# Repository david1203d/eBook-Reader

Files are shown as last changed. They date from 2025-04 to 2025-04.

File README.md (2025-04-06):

# 📘 Ebook Reader cu ESP32-C6

Acest proiect este un **Ebook Reader portabil**, cu consum redus, bazat pe **ESP32-C6** și ecran **E-Paper**, ideal pentru lectură prelungită.  
Dispozitivul citește fișiere `.txt` de pe un card **microSD** și permite navigarea cu **butoane fizice**, având alimentare din **baterie Li-Po** și opțional monitorizare a nivelului acesteia.

---

## 📦 Bill of Materials (BOM)

| Componentă | Model/Tip | Link comandă | Datasheet |
|---|---|---|---|
| Microcontroller | ESP32-C6 | Mouser | [ESP32-C6](#)  |
| Ecran | E-Paper Display 2.9" | Comet | [GDEH029A1](#) |
| Cart Reader | MicroSD SPI module | Mouser | [Modul SD](#)  |
| Senzor de mediu | BME688 | Mouser | [BME688](#) |
| RTC | DS3231SN | Mouser | [DS3231](#) |
| Battery Monitor | MAX17048 | Mouser | [MAX17048](#)  |
| Flash extern | W25Q512JV (64MB) | Mouser | [W25Q512JV](#) |
| Regulator tensiune | MCP1826S-3302E/DB | Mouser | [MCP1826](#) |
| BMS | TP4056 | Comet | [TP4056](#) |
| Butoane | Tactile Switches | Comet | [SKQG](#) |

---

## ⚙️ Funcționalitate Hardware

### 1. ESP32-C6
- Interfață principală: SPI, I2C, GPIO  
- Flash extern NOR (64MB) prin QSPI  
- UART pentru debug  
- Alimentare 3.3V prin LDO

### 2. E-Paper Display
- Alimentat prin EPD Power Driver (boost + FET)  
- Conectat prin SPI la ESP32-C6  
- Pini dedicați: DIN, CLK, CS, DC, RST, BUSY

### 3. Modul SD Card
- Interfață SPI  
- Stocare fișiere `.txt`

### 4. RTC DS3231SN
- I2C cu backup battery (CR2032)  
- Oră exactă cu temperatură compensată

### 5. Senzor BME688
- I2C – temperatură, presiune, umiditate, calitate aer  
- Util pentru monitorizare ambientală (opțional)

### 6. MAX17048
- Monitorizare nivel baterie prin I2C  
- Poate afișa procentul pe ecran

### 7. TP4056 Charging
- Încărcare Li-Po prin USB-C  
- Protecție la supradescărcare/supraincărcare

---

## 📌 Pini ESP32-C6 Utilizați

| Pin ESP32-C6 | Funcție hardware | Componentă |
|---|---|---|
| GPIO0 | I2C SCL | BME688, MAX17048, DS3231 |
| GPIO1 | I2C SDA | BME688, MAX17048, DS3231 |
| GPIO2 | SPI MOSI | E-paper, SD, Flash |
| GPIO3 | SPI MISO | SD, Flash |
| GPIO4 | SPI CLK | E-paper, SD, Flash |
| GPIO5 | SPI CS (e-paper) | E-paper |
| GPIO6 | SPI CS (SD card) | SD Card |
| GPIO7 | SPI CS (Flash extern) | W25Q512JV |
| GPIO8 | GPIO Buton 1 | Pag. înainte |
| GPIO9 | GPIO Buton 2 | Pag. înapoi |
| GPIO10 | GPIO Buton 3 | Reset/Menu |
| GPIO11 | UART TX | Debug UART |
| GPIO12 | UART RX | Debug UART |

---

## 🖼️ Design PCB & Randări

- **PCB**: 2 straturi, dimensiuni: `92.2mm x 67.2mm`  
- **Componente** poziționate compact pentru portabilitate  
- **Acces ușor** la card microSD, USB-C și butoane  
- **Protecție ESD** pe liniile USB și SPI  

## ✅ Alte Detalii Relevante

- **Mod Deep Sleep**: activat după 30s de inactivitate  
- **W25Q512JV Flash extern**: stocare rapidă pentru sute de cărți `.txt`  
- **Qwiic/Stemma QT header**: pentru expansiune cu alte periferice  
- **Test Pads**: depanare & validare semnal

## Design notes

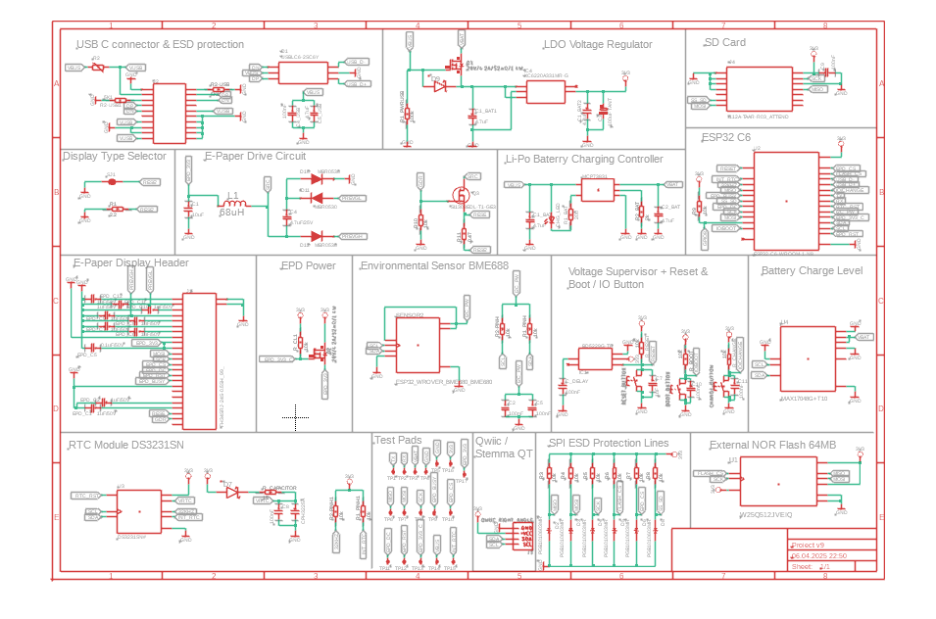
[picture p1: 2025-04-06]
Images/Schematic.PNG

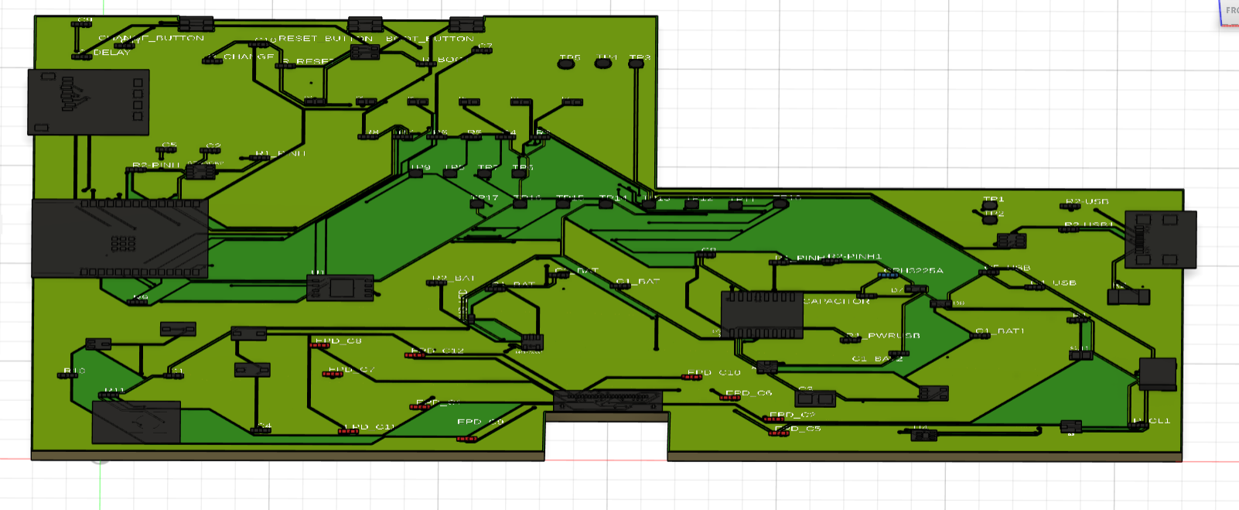
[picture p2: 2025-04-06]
Images/Placa3D.PNG

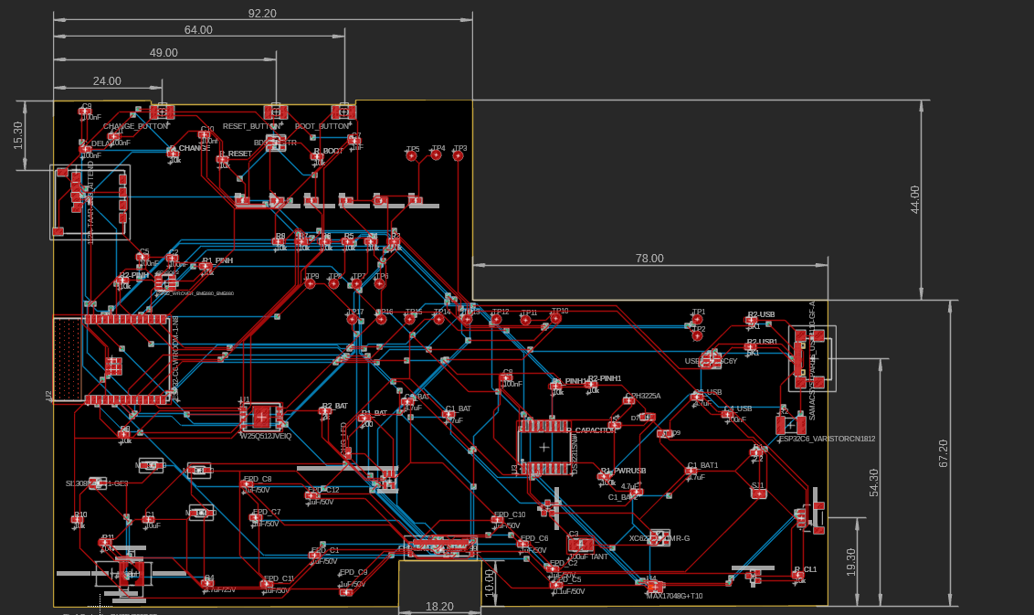
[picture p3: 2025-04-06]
Images/PCB.png

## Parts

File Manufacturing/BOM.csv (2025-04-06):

Qty | Value | Device | Package | Parts | Description | ARROW_PART_NUMBER | ARROW_PRICE-STOCK | AVAILABILITY | CENTROID_NOT_SPECIFIED | CHECK_PRICES | COPYRIGHT | DATASHEET | DESCRIPTION | DIGIKEY_DESCRIPTION | DIGIKEY_PART_NUMBER | HEIGHT | LEAD_FREE | MANUFACTURER_NAME | MANUFACTURER_PART_NUMBER | MF | MFR_NAME | MOUSER_PART_NUMBER | MOUSER_PRICE-STOCK | MOUSER_TESTING_PART_NUMBER | MOUSER_TESTING_PRICE-STOCK | MP | MPN | PACKAGE | POPULARITY | PREFIX | PRICE | PROD_ID | PURCHASE-URL | ROHS | SNAPEDA_LINK | SPICEMODEL | SPICEPREFIX | TEMPERATURE_RANGE_HIGH | TEMPERATURE_RANGE_LOW | TP_SIGNAL_NAME | VALUE
1 |  | ADAFRUIT_LEDCHIP-LED0603 | ADAFRUIT_CHIP-LED0603 | CHG_LED | LED
1 |  | EAGLE-LTSPICE_CC0402 | EAGLE-LTSPICE_C0402 | CPH3225A | CAPACITOR, European symbol |  |  |  |  |  |  |  |  |  |  |  |  |  |  |  |  |  |  |  |  |  |  |  |  |  |  |  |  |  |  | NONE | C
1 |  | SJ | SJ | SJ1 | SMD solder JUMPER |  |  |  |  |  |  |  |  |  |  |  |  |  |  |  |  |  |  |  |  |  |  |  | 3
1 | 0.1uF/50V | EAGLE-LTSPICE_CC0402 | EAGLE-LTSPICE_C0402 | EPD_C5 | CAPACITOR, European symbol |  |  |  |  |  |  |  |  |  |  |  |  |  |  |  |  |  |  |  |  |  |  |  |  |  |  |  |  |  |  | NONE | C
1 | 0.47 | ESP32_WROVER_EAGLE-LTSPICE_RR0402 | ESP32_WROVER_EAGLE-LTSPICE_R0402 | R11 | RESISTOR, European symbol |  |  |  |  |  |  |  |  |  |  |  |  |  |  |  |  |  |  |  |  |  |  |  |  |  |  |  |  |  |  | NONE | R
1 | 100k | ESP32_WROVER_EAGLE-LTSPICE_RR0402 | ESP32_WROVER_EAGLE-LTSPICE_R0402 | R1_PWRUSB | RESISTOR, European symbol |  |  |  |  |  |  |  |  |  |  |  |  |  |  |  |  |  |  |  |  |  |  |  |  |  |  |  |  |  |  | NONE | R
1 | 100nF | EAGLE-LTSPICE_CC0402 | EAGLE-LTSPICE_C0402 | C8 | CAPACITOR, European symbol |  |  |  |  |  |  |  |  |  |  |  |  |  |  |  |  |  |  |  |  |  |  |  |  |  |  |  |  |  |  | NONE | C
6 | 100nF | ESP32_WROVER_EAGLE-LTSPICE_CC0402 | ESP32_WROVER_EAGLE-LTSPICE_C0402 | C2, C4_USB, C5, C9, C11, C_DELAY | CAPACITOR, European symbol |  |  |  |  |  |  |  |  |  |  |  |  |  |  |  |  |  |  |  |  |  |  |  |  |  |  |  |  |  |  | NONE | C
1 | 100nf | ESP32_WROVER_EAGLE-LTSPICE_CC0402 | ESP32_WROVER_EAGLE-LTSPICE_C0402 | C10 | CAPACITOR, European symbol |  |  |  |  |  |  |  |  |  |  |  |  |  |  |  |  |  |  |  |  |  |  |  |  |  |  |  |  |  |  | NONE | C
1 | 100uF TANT | RCL_CPOL-EUCT3528 | RCL_CT3528 | C3 | POLARIZED CAPACITOR, European symbol |  |  |  |  |  |  |  |  |  |  |  |  |  |  |  |  |  |  |  |  |  |  |  | 0 |  |  |  |  |  |  |  | C
16 | 10k | ESP32_WROVER_EAGLE-LTSPICE_RR0402 | ESP32_WROVER_EAGLE-LTSPICE_R0402 | R1_PINH, R1_PINH1, R2-PINH, R2-PINH1, R3, R4, R5, R6, R7, R8, R9, R10, R_BOOT, R_CHANGE, R_CL1, R_RESET | RESISTOR, European symbol |  |  |  |  |  |  |  |  |  |  |  |  |  |  |  |  |  |  |  |  |  |  |  |  |  |  |  |  |  |  | NONE | R
1 | 10uF | ESP32_WROVER_EAGLE-LTSPICE_CC0402 | ESP32_WROVER_EAGLE-LTSPICE_C0402 | C1 | CAPACITOR, European symbol |  |  |  |  |  |  |  |  |  |  |  |  |  |  |  |  |  |  |  |  |  |  |  |  |  |  |  |  |  |  | NONE | C
1 | 112A-TAAR-R03_ATTEND | 112A-TAAR-R03_ATTEND | 112ATAARR03ATTEND | J4 | Micro SD Card Socket, Push-Push Type, Top Mount, SMT, H=1.83mm, 10u |  |  |  |  |  |  |  | Micro SD Card Socket | Push-Push Type | Top Mount | SMT | H=1.83mm | 10u |  |  | 1.9mm |  | ATTEND | 112A-TAAR-R03 ATTEND
1 | 15 | ESP32_WROVER_EAGLE-LTSPICE_RR0402 | ESP32_WROVER_EAGLE-LTSPICE_R0402 | R_CAPACITOR | RESISTOR, European symbol |  |  |  |  |  |  |  |  |  |  |  |  |  |  |  |  |  |  |  |  |  |  |  |  |  |  |  |  |  |  | NONE | R
1 | 1uF | ESP32_WROVER_EAGLE-LTSPICE_CC0402 | ESP32_WROVER_EAGLE-LTSPICE_C0402 | C7 | CAPACITOR, European symbol |  |  |  |  |  |  |  |  |  |  |  |  |  |  |  |  |  |  |  |  |  |  |  |  |  |  |  |  |  |  | NONE | C
9 | 1uF/50V | EAGLE-LTSPICE_CC0402 | EAGLE-LTSPICE_C0402 | EPD_C1, EPD_C2, EPD_C6, EPD_C7, EPD_C8, EPD_C9, EPD_C10, EPD_C11, EPD_C12 | CAPACITOR, European symbol |  |  |  |  |  |  |  |  |  |  |  |  |  |  |  |  |  |  |  |  |  |  |  |  |  |  |  |  |  |  | NONE | C
1 | 2.2 | ESP32_WROVER_EAGLE-LTSPICE_RR0402 | ESP32_WROVER_EAGLE-LTSPICE_R0402 | R1 | RESISTOR, European symbol |  |  |  |  |  |  |  |  |  |  |  |  |  |  |  |  |  |  |  |  |  |  |  |  |  |  |  |  |  |  | NONE | R
1 | 200 | ESP32_WROVER_EAGLE-LTSPICE_RR0402 | ESP32_WROVER_EAGLE-LTSPICE_R0402 | R1_BAT | RESISTOR, European symbol |  |  |  |  |  |  |  |  |  |  |  |  |  |  |  |  |  |  |  |  |  |  |  |  |  |  |  |  |  |  | NONE | R
2 | 20V/4.2A/52mO/1.4W | ESP32_WROVER_SPARKFUN-DISCRETESEMI_MOSFET_PCH-DMG2305UX-7 | ESP32_WROVER_SPARKFUN-DISCRETESEMI_SOT23-3 | Q1, Q2 | P-channel MOSFETs |  |  |  |  |  |  |  |  |  |  |  |  |  |  |  |  |  |  |  |  |  |  |  |  |  |  | TRAN-14388 |  |  |  |  |  |  |  |  | 20V/4.2A/52mO/1.4W
1 | 2k | ESP32_WROVER_EAGLE-LTSPICE_RR0402 | ESP32_WROVER_EAGLE-LTSPICE_R0402 | R2_BAT | RESISTOR, European symbol |  |  |  |  |  |  |  |  |  |  |  |  |  |  |  |  |  |  |  |  |  |  |  |  |  |  |  |  |  |  | NONE | R
5 | 4.7uF | ESP32_WROVER_EAGLE-LTSPICE_CC0402 | ESP32_WROVER_EAGLE-LTSPICE_C0402 | C1_BAT, C1_BAT1, C1_BAT2, C2_BAT, C5_USB | CAPACITOR, European symbol |  |  |  |  |  |  |  |  |  |  |  |  |  |  |  |  |  |  |  |  |  |  |  |  |  |  |  |  |  |  | NONE | C
1 | 4.7uF/25V | ESP32_WROVER_EAGLE-LTSPICE_CC0402 | ESP32_WROVER_EAGLE-LTSPICE_C0402 | C4 | CAPACITOR, European symbol |  |  |  |  |  |  |  |  |  |  |  |  |  |  |  |  |  |  |  |  |  |  |  |  |  |  |  |  |  |  | NONE | C
2 | 5K1 | ESP32_WROVER_EAGLE-LTSPICE_RR0402 | ESP32_WROVER_EAGLE-LTSPICE_R0402 | R2-USB, R2-USB1 | RESISTOR, European symbol |  |  |  |  |  |  |  |  |  |  |  |  |  |  |  |  |  |  |  |  |  |  |  |  |  |  |  |  |  |  | NONE | R
1 | 68uH | 744043680IND_4828-WE-TPC_WRE | IND_4828-WE-TPC_WRE | L1 |  |  |  |  |  |  | Copyright (C) 2024 Ultra Librarian. All rights reserved. |  |  |  |  |  |  |  | 744043680 |  | Wurth Electronics
1 | BD5229G-TR | BD5229G-TR | SOT95P280X125-5N | IC1 | Voltage Detector with Adjustable Delay Time: CMOS processes are utilized to develop high precision, low current consumption CMOS reset ICs that allow arbitrary setting of the delay time. The extensive lineup includes both Nch Open Drain and CMOS output types in a wide range of detection voltages (from 2.3V to 6.0V, in 0.1V steps), enabling selection of the ideal solution based on customer requirements. In addition, the entire series is of course both lead-free and RoHS-compliant. |  |  |  |  |  |  |  | Voltage Detector with Adjustable Delay Time: CMOS processes are utilized to develop high precision | low current consumption CMOS reset ICs that allow arbitrary setting of the delay time. The extensive lineup includes both Nch Open Drain and CMOS output types in a wide range of detection voltages (from 2.3V to 6.0V | in 0.1V steps) | enabling selection of the ideal solution based on customer requirements. In addition | the entire series is of course both lead-free and RoHS-compliant. |  |  | 1.25mm |  | ROHM Semiconductor | BD5229G-TR |  |  | 755-BD5229G-TR | https://www.mouser.co.uk/ProductDetail/ROHM-Semiconductor/BD5229G-TR?qs=4kLU8WoGk0vvnhrrYwdszw%3D%3D
3 | BUTTON_CUSYOMV1 | BUTTON_CUSYOMV1 | MYBUTTON | BOOT_BUTTON, CHANGE_BUTTON, RESET_BUTTON
1 | DS3231SN# | DS3231SN# | SOIC127P1032X265-16N | U3 | Real Time Clock Serial 16-Pin SOIC W T/R Check availability |  |  | In Stock |  | https://www.snapeda.com/parts/DS3231SN%23/Analog+Devices/view-part/?ref=eda |  |  | Extremely Accurate I²C-Integrated RTC/TCXO/Crystal |  |  |  |  |  |  | Analog Devices |  |  |  |  |  | DS3231SN# |  | SOIC-16 Maxim |  |  | None |  | https://www.snapeda.com/api/url_track_click_mouser/?unipart_id=99048&manufacturer=Analog Devices&part_name=DS3231SN#&search_term=None |  | https://www.snapeda.com/parts/DS3231SN%23/Analog+Devices/view-part/?ref=snap
1 | ESP32-C6-WROOM-1-N8 | ESP32-C6-WROOM-1-N8 | XCVR_ESP32-C6-WROOM-1-N8 | U2 | Check availability |  |  | In Stock |  | https://www.snapeda.com/parts/ESP32-C6-WROOM-1-N8/Espressif+Systems/view-part/?ref=eda |  |  | Multiprotocol Modules ESP32-C6 module | Wi-Fi 6 in 2.4 GHz band | Bluetooth 5 | Zigbee 3.0 and Thread. ESP34-WROOM Compatible - ENGINEERING SAMPLE |  |  |  |  |  |  | Espressif Systems |  |  |  |  |  | ESP32-C6-WROOM-1-N8 |  | None |  |  | None |  |  |  | https://www.snapeda.com/parts/ESP32-C6-WROOM-1-N8/Espressif+Systems/view-part/?ref=snap
1 | ESP32C6_VARISTORCN1812 | ESP32C6_VARISTORCN1812 | ESP32C6_VARISTOR_CT/CN1812 | R2 | VARISTOR |  |  |  |  |  |  |  |  |  |  |  |  |  |  |  |  |  |  |  |  |  |  |  | 0
2 | ESP32_WROVER_AVX---SD0805S020S1R0_AVX_SD0805S020S1R0_0_0AVX_SD0805S020S1R0_0_0 | ESP32_WROVER_AVX---SD0805S020S1R0_AVX_SD0805S020S1R0_0_0AVX_SD0805S020S1R0_0_0 | ESP32_WROVER_AVX---SD0805S020S1R0_AVX_SD0805S020S1R0_0 | D7, D9 | Schottky Barrier Rectifier Diode |  |  |  | No |  |  | http://datasheets.avx.com/schottky.pdf |  | DIODE SCHOTTKY 20V 1A 0805 | 478-7800-1-ND |  | yes |  |  | AVX |  | 581-SD0805S020S1R0 |  |  |  |  |  | 0805 (2012 metric) |  | D |  |  |  | yes |  |  |  | +125°C | -55°C
1 | ESP32_WROVER_BME680_BME680 | ESP32_WROVER_BME680_BME680 | ESP32_WROVER_BME680_PSON80P300X300X100-8N | SENSOR2 | Integrated Environmental Unit |  |  | Unavailable |  |  |  |  | Integrated Environmental Unit |  |  |  |  |  |  | Bosch Sensortec |  |  |  |  |  | BME680 |  | LGA-8 Bosch Tools |  |  | None
1 | ESP32_WROVER_SPARKFUN-IC-POWER_MCP73831 | ESP32_WROVER_SPARKFUN-IC-POWER_MCP73831 | ESP32_WROVER_SPARKFUN-IC-POWER_SOT23-5 | MCP73831 | MCP73831T Li-Ion, Li-Pol Controller |  |  |  |  |  |  |  |  |  |  |  |  |  |  |  |  |  |  |  |  |  |  |  |  |  |  | IC-09995
1 | FH34SRJ-24S-0.5SH_99_ | FH34SRJ-24S-0.5SH_99_ | FH34SRJ24S05SH99 | J1 | (0.50mm) Surface Mount, Right Angle |  |  |  |  |  |  |  | 24 Position FFC | FPC Connector Contacts | (0.50mm) Surface Mount | Right Angle |  |  | 1.1mm |  | Hirose | FH34SRJ-24S-0.5SH(99) |  |  | 798-FH34SRJ24S05SH99 | https://www.mouser.co.uk/ProductDetail/Hirose-Connector/FH34SRJ-24S-0.5SH99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
1 | MAX17048G+T10 | MAX17048G+T10 | SON50P200X200X80-9N | U4 | Check availability |  |  | In Stock |  | https://www.snapeda.com/parts/MAX17048G+T10/Analog+Devices/view-part/?ref=eda |  |  | 3µA 1-Cell/2-Cell Fuel Gauge with ModelGauge |  |  |  |  |  |  | Analog Devices |  |  |  |  |  | MAX17048G+T10 |  | TDFN-8 Maxim |  |  | None |  | https://www.snapeda.com/api/url_track_click_mouser/?unipart_id=329239&manufacturer=Analog Devices&part_name=MAX17048G+T10&search_term=None |  | https://www.snapeda.com/parts/MAX17048G+T10/Analog+Devices/view-part/?ref=snap
3 | MBR0530 | MBR0530 | SOD3716X135N | D10, D11, D12 | ON SEMICONDUCTOR - MBR0530 - DIODE, SCHOTTKY, 0.5A, 30V, SOD-123 |  |  | In Stock |  | https://www.snapeda.com/parts/MBR0530/Onsemi/view-part/?ref=eda |  |  | Diode Schottky 30 V 500mA Surface Mount SOD-123 |  |  |  |  |  |  | ON Semiconductor |  |  |  |  |  | MBR0530 |  | SOD-123-2 ON Semiconductor |  |  | None |  | https://www.snapeda.com/api/url_track_click_mouser/?unipart_id=179458&manufacturer=ON Semiconductor&part_name=MBR0530&search_term=None |  | https://www.snapeda.com/parts/MBR0530/Onsemi/view-part/?ref=snap
6 | PGB1010603MR | PGB1010603MR | DIOC1608X36N | D2, D3, D4, D5, D6, D8 | Check availability |  |  | In Stock |  | https://www.snapeda.com/parts/PGB1010603MR/Littelfuse/view-part/?ref=eda |  |  | 150V (Typ) Clamp - Ipp Tvs Diode Surface Mount 0603 (1608 Metric) |  |  |  |  |  |  | Littelfuse Inc. |  |  |  |  |  | PGB1010603MR |  | 0603 Littelfuse Inc. |  |  | None |  | https://www.snapeda.com/api/url_track_click_mouser/?unipart_id=5659453&manufacturer=Littelfuse Inc.&part_name=PGB1010603MR&search_term=None |  | https://www.snapeda.com/parts/PGB1010603MR/Littelfuse/view-part/?ref=snap
1 | QWIIC_RIGHT_ANGLE | QWIIC_CONNECTORJS-1MM | JST04_1MM_RA | J3 | SparkFun I2C Standard Qwiic Connector |  |  |  |  |  |  |  |  |  |  |  |  |  |  |  |  |  |  |  |  |  |  |  |  |  |  | CONN-13694 |  |  |  |  |  |  |  |  | QWIIC_RIGHT_ANGLE
1 | SAMACSYS_PARTS_USB4110-GF-A | SAMACSYS_PARTS_USB4110-GF-A | SAMACSYS_PARTS_USB4110GFA | J2 | CONN USB 2.0 TYPE-C R/A SMT |  |  |  |  |  |  |  | CONN USB 2.0 TYPE-C R/A SMT |  |  | 3.26mm |  | GCT (GLOBAL CONNECTOR TECHNOLOGY) | USB4110-GF-A |  |  | 640-USB4110-GF-A | https://www.mouser.co.uk/ProductDetail/GCT/USB4110-GF-A?qs=KUoIvG%2F9IlYiZvIXQjyJeA%3D%3D
1 | SI1308EDL-T1-GE3 | SI1308EDL-T1-GE3 | SOT65P210X110-3N | Q3 | MOSFET N-Ch 30V 1.5A TrenchFET SC70 Vishay Si1308EDL-T1-GE3 N-channel MOSFET Transistor, 1.5 A, 30 V, 3-Pin SC-70 |  |  | In Stock |  | https://www.snapeda.com/parts/SI1308EDL-T1-GE3/Vishay+Siliconix/view-part/?ref=eda |  |  | Si1308EDL-T1-GE3 N-channel MOSFET Transistor | 1.5 A | 30 V | 3-Pin SC-70 | Siliconix / Vishay SI1308EDL-T1-GE3 |  |  |  |  |  |  | Vishay Siliconix |  |  |  |  |  | SI1308EDL-T1-GE3 |  | SOT-323 Vishay Semiconductor |  |  | None |  | https://www.snapeda.com/api/url_track_click_mouser/?unipart_id=274603&manufacturer=Vishay Siliconix&part_name=SI1308EDL-T1-GE3&search_term=None |  | https://www.snapeda.com/parts/SI1308EDL-T1-GE3/Vishay+Siliconix/view-part/?ref=snap
17 | TPTP20R | TPTP20R | TP20R | TP1, TP2, TP3, TP4, TP5, TP6, TP7, TP8, TP9, TP10, TP11, TP12, TP13, TP14, TP15, TP16, TP17 | Test pad |  |  |  |  |  |  |  |  |  |  |  |  |  |  |  |  |  |  |  |  |  |  |  | 2
1 | USBLC6-2SC6Y | USBLC6-2SC6Y | SOT95P280X145-6N | D1 | Low Cap. ESD Protection Auto SOT-23-6 STMicroelectronics USBLC6-2SC6Y, Dual Uni-Directional TVS Diode Array, 6-Pin SOT-23 |  |  | In Stock |  | https://www.snapeda.com/parts/USBLC6-2SC6Y/STMicroelectronics/view-part/?ref=eda |  |  | 17V Clamp 5A (8/20µs) Ipp Tvs Diode Surface Mount SOT-23-6 |  |  |  |  |  |  | STMicroelectronics |  |  |  |  |  | USBLC6-2SC6Y |  | SOT-23-6 STMicroelectronics |  |  | None |  |  |  | https://www.snapeda.com/parts/USBLC6-2SC6Y/STMicroelectronics/view-part/?ref=snap
1 | W25Q512JVEIQ | W25Q512JVEIQ | SON127P600X800X80-9N | U1 | Check availability |  |  | In Stock |  | https://www.snapeda.com/parts/W25Q512JVEIQ/Winbond+Electronics/view-part/?ref=eda |  |  | FLASH - NOR Memory IC 512Mb (64M x 8) SPI - Quad I/O 133 MHz 8-WSON (8x6) |  |  |  |  |  |  | Winbond Electronics |  |  |  |  |  | W25Q512JVEIQ |  | Package |  |  | None |  |  |  | https://www.snapeda.com/parts/W25Q512JVEIQ/Winbond+Electronics/view-part/?ref=snap
1 | XC6220A331MR-G | XC6220A331MR-G | SOT95P280X120-5N | IC4 | LDO Voltage Regulators |  |  |  |  |  |  |  | LDO Voltage Regulators |  |  | 1.2mm |  | Torex | XC6220A331MR-G |  |  | 865-XC6220A331MR-G | https://www.mouser.co.uk/ProductDetail/Torex-Semiconductor/XC6220A331MR-G?qs=AsjdqWjXhJ8ZSWznL1J0gg%3D%3D

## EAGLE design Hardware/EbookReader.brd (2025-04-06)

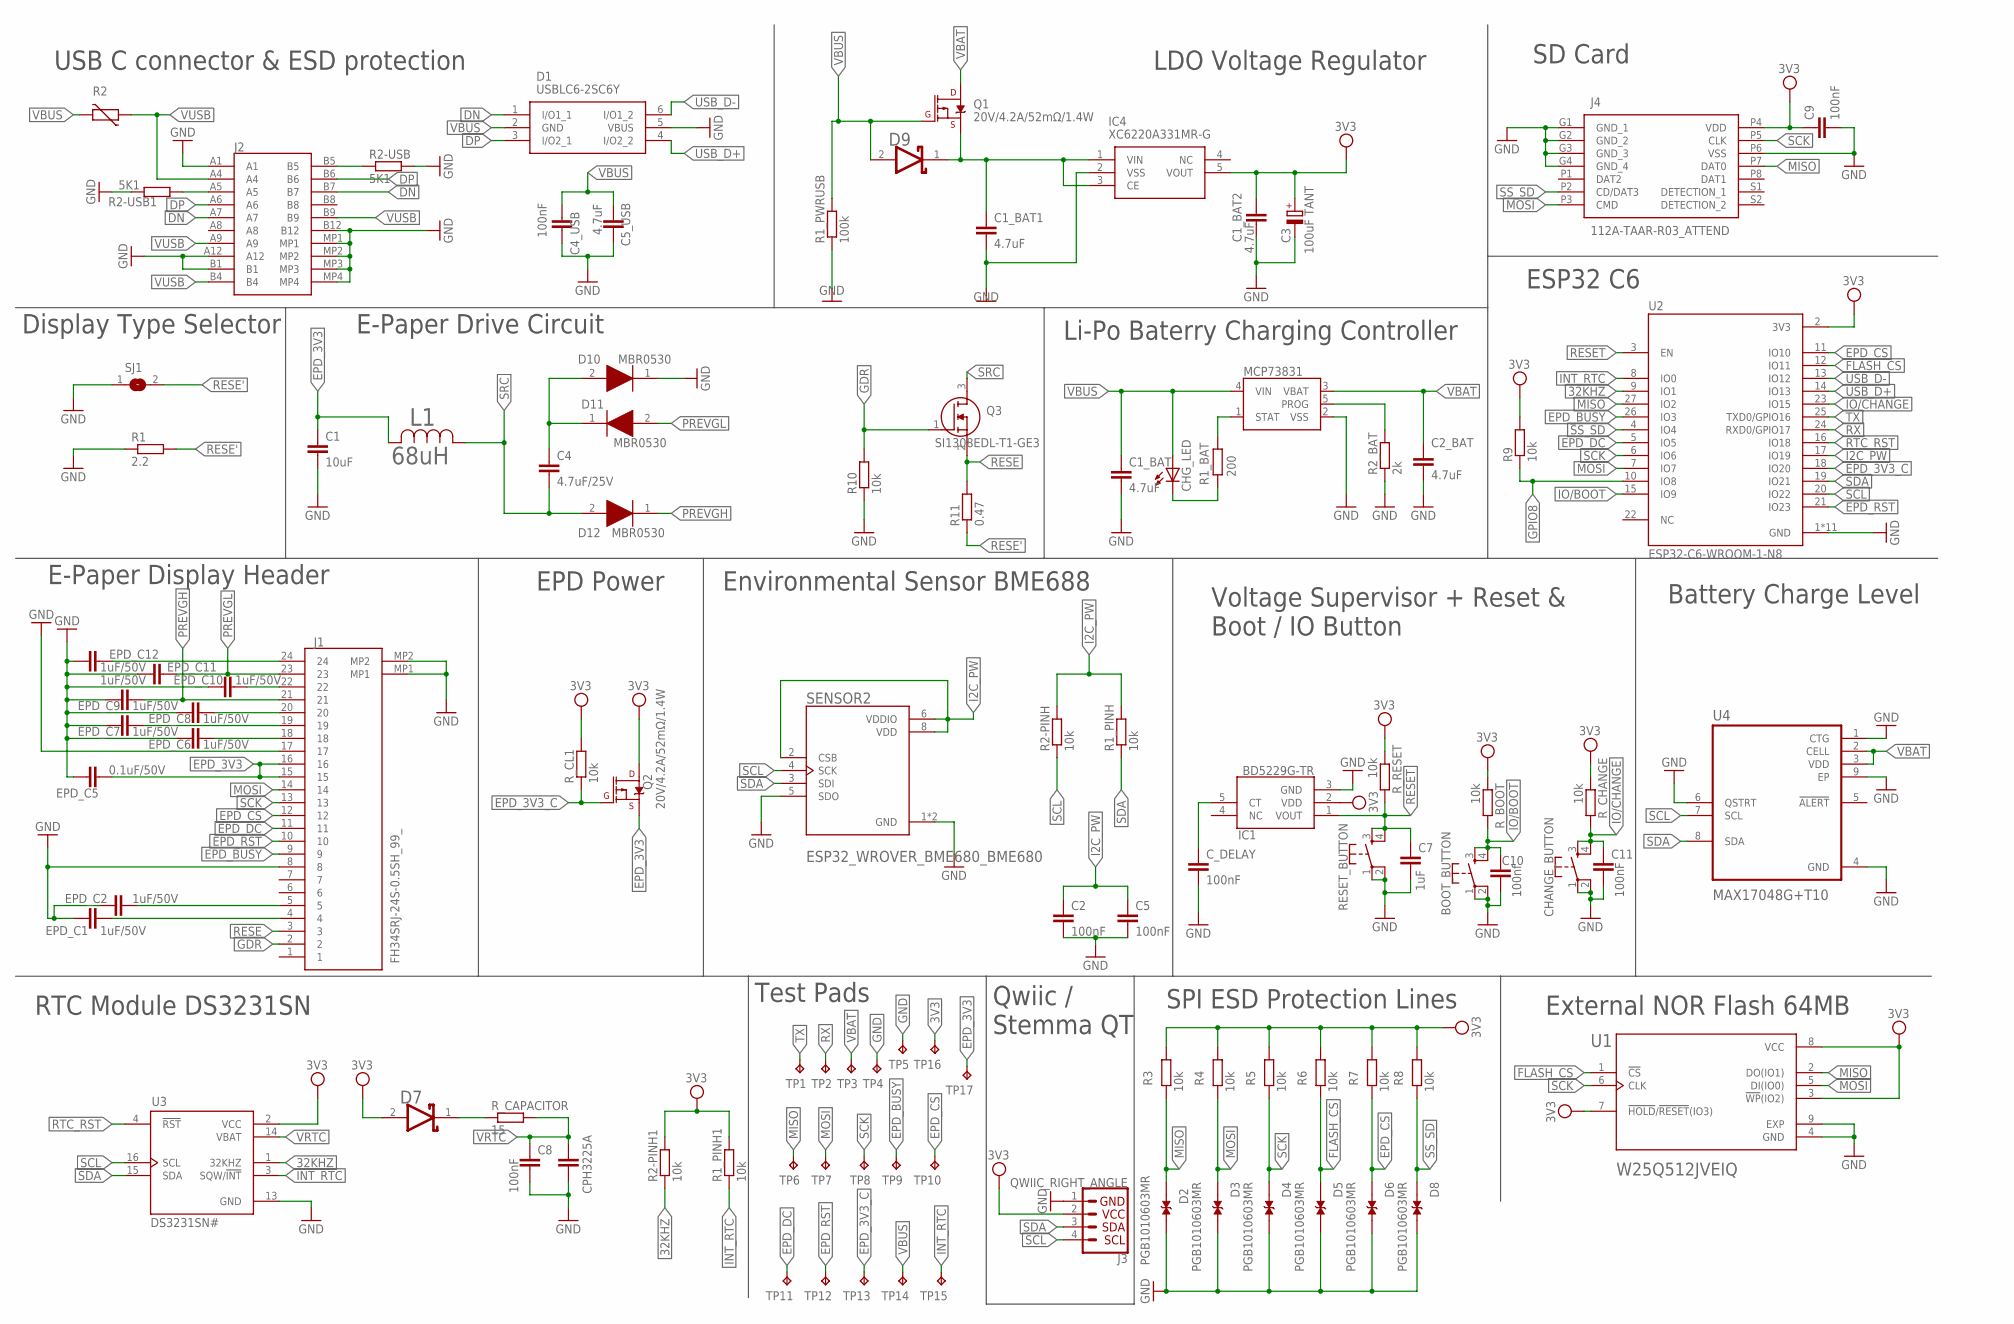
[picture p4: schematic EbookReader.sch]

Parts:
BOOT_BUTTON: BUTTON_CUSYOMV1; MYBUTTON
C1: 10uF; ESP32_WROVER_EAGLE-LTSPICE_C0402
C1_BAT, C1_BAT1, C1_BAT2, C2_BAT, C5_USB: 4.7uF; ESP32_WROVER_EAGLE-LTSPICE_C0402
C2, C4_USB, C5, C9, C11: 100nF; ESP32_WROVER_EAGLE-LTSPICE_C0402
C3: 100uF TANT; RCL_CT3528
C4: 4.7uF/25V; ESP32_WROVER_EAGLE-LTSPICE_C0402
C7: 1uF; ESP32_WROVER_EAGLE-LTSPICE_C0402
C8: 100nF; EAGLE-LTSPICE_C0402
C10: 100nf; ESP32_WROVER_EAGLE-LTSPICE_C0402
CHANGE_BUTTON: BUTTON_CUSYOMV1; MYBUTTON
CHG_LED: ADAFRUIT_LEDCHIP-LED0603; ADAFRUIT_CHIP-LED0603
CPH3225A: EAGLE-LTSPICE_CC0402; EAGLE-LTSPICE_C0402
C_DELAY: 100nF; ESP32_WROVER_EAGLE-LTSPICE_C0402
D1: USBLC6-2SC6Y; SOT95P280X145-6N
D2, D3, D4, D5, D6, D8: PGB1010603MR; DIOC1608X36N
D7, D9: ESP32_WROVER_AVX---SD0805S020S1R0_AVX_SD0805S020S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; ESP32_WROVER_AVX---SD0805S020S1R0_AVX_SD0805S020S1R0_0
D10, D11, D12: MBR0530; SOD3716X135N
EPD_C1, EPD_C2, EPD_C6, EPD_C7, EPD_C8, EPD_C9, EPD_C10, EPD_C11, EPD_C12: 1uF/50V; EAGLE-LTSPICE_C0402
EPD_C5: 0.1uF/50V; EAGLE-LTSPICE_C0402
IC1: BD5229G-TR; SOT95P280X125-5N
IC4: XC6220A331MR-G; SOT95P280X120-5N
J1: FH34SRJ-24S-0.5SH_99_; FH34SRJ24S05SH99
J2: SAMACSYS_PARTS_USB4110-GF-A; SAMACSYS_PARTS_USB4110GFA
J3: QWIIC_RIGHT_ANGLE; JST04_1MM_RA
J4: 112A-TAAR-R03_ATTEND; 112ATAARR03ATTEND
L1: 68uH; IND_4828-WE-TPC_WRE
MCP73831: ESP32_WROVER_SPARKFUN-IC-POWER_MCP73831; ESP32_WROVER_SPARKFUN-IC-POWER_SOT23-5
Q1, Q2: 20V/4.2A/52mΩ/1.4W; ESP32_WROVER_SPARKFUN-DISCRETESEMI_SOT23-3
Q3: SI1308EDL-T1-GE3; SOT65P210X110-3N
R1: 2.2; ESP32_WROVER_EAGLE-LTSPICE_R0402
R1_BAT: 200; ESP32_WROVER_EAGLE-LTSPICE_R0402
R1_PINH, R1_PINH1, R2-PINH, R2-PINH1, R3, R4, R5, R6, R7, R8, R9, R10: 10k; ESP32_WROVER_EAGLE-LTSPICE_R0402
R1_PWRUSB: 100k; ESP32_WROVER_EAGLE-LTSPICE_R0402
R2: ESP32C6_VARISTORCN1812; ESP32C6_VARISTOR_CT/CN1812
R2-USB, R2-USB1: 5K1; ESP32_WROVER_EAGLE-LTSPICE_R0402
R2_BAT: 2k; ESP32_WROVER_EAGLE-LTSPICE_R0402
R11: 0.47; ESP32_WROVER_EAGLE-LTSPICE_R0402
RESET_BUTTON: BUTTON_CUSYOMV1; MYBUTTON
R_BOOT: 10k; ESP32_WROVER_EAGLE-LTSPICE_R0402
R_CAPACITOR: 15; ESP32_WROVER_EAGLE-LTSPICE_R0402
R_CHANGE: 10k; ESP32_WROVER_EAGLE-LTSPICE_R0402
R_CL1: 10k; ESP32_WROVER_EAGLE-LTSPICE_R0402
R_RESET: 10k; ESP32_WROVER_EAGLE-LTSPICE_R0402
SENSOR2: ESP32_WROVER_BME680_BME680; ESP32_WROVER_BME680_PSON80P300X300X100-8N
SJ1: SJ
TP1, TP2, TP3, TP4, TP5, TP6, TP7, TP8, TP9, TP10, TP11, TP12, TP13, TP14, TP15, TP16, TP17: TPTP20R; TP20R
U1: W25Q512JVEIQ; SON127P600X800X80-9N
U2: ESP32-C6-WROOM-1-N8; XCVR_ESP32-C6-WROOM-1-N8
U3: DS3231SN#; SOIC127P1032X265-16N
U4: MAX17048G+T10; SON50P200X200X80-9N

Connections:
3V3: C1_BAT2.1, C3.+, C9.1, D7.2 (ANODE), IC1.2 (VDD), IC4.5 (VOUT), J3.2, J4.P4 (VDD), Q2.3 (D), R1_PINH1.2, R2-PINH1.2, R3.2, R4.2, R5.2, R6.2, R7.2, R8.2, R9.2, R_BOOT.1, R_CHANGE.1, R_CL1.2, R_RESET.1, TP16.TP, U1.3 (!WP!(IO2)), U1.7 (!HOLD!/!RESET!(IO3)), U1.8 (VCC), U2.2 (3V3), U3.2 (VCC)
32KHZ: R2-PINH1.1, U2.9 (IO1), U3.1 (32KHZ)
DN: D1.1 (I/O1_1), J2.A7, J2.B7
DP: D1.3 (I/O2_1), J2.A6, J2.B6
EPD_3V3: C1.1, EPD_C5.1, J1.15, J1.16, L1.2, Q2.2 (S), TP17.TP
EPD_3V3_C: Q2.1 (G), R_CL1.1, TP13.TP, U2.18 (IO20)
EPD_BUSY: J1.9, TP9.TP, U2.26 (IO3)
EPD_CS: D6.1, J1.12, R7.1, TP10.TP, U2.11 (IO10)
EPD_DC: J1.11, TP11.TP, U2.5 (IO5)
EPD_RST: J1.10, TP12.TP, U2.21 (IO23)
FLASH_CS: D5.1, R6.1, U1.1 (!CS), U2.12 (IO11)
GDR: J1.2, Q3.1 (G), R10.2
GND: BOOT_BUTTON.1, BOOT_BUTTON.2, C1.2, C1_BAT.2, C1_BAT1.2, C1_BAT2.2, C2.2, C2_BAT.2, C3.-, C4_USB.2, C5.2, C5_USB.2, C7.2, C8.2, C9.2, C10.2, C11.2, CHANGE_BUTTON.1, CHANGE_BUTTON.2, CPH3225A.2, C_DELAY.2, D1.5 (VBUS), D2.2, D3.2, D4.2, D5.2, D6.2, D8.2, D10.1 (K), EPD_C1.2, EPD_C2.2, EPD_C5.2, EPD_C6.2, EPD_C7.2, EPD_C8.2, EPD_C9.2, EPD_C10.2, EPD_C11.2, EPD_C12.2, IC1.3 (GND), IC4.2 (VSS), J1.8, J1.17, J1.MP1, J1.MP2, J2.A1, J2.A12, J2.B1, J2.B12, J2.MP1, J2.MP2, J2.MP3, J2.MP4, J3.1, J4.G1 (GND_1), J4.G2 (GND_2), J4.G3 (GND_3), J4.G4 (GND_4), J4.P6 (VSS), MCP73831.2 (VSS), R1.1, R1_PWRUSB.1, R2-USB.2, R2-USB1.1, R2_BAT.1, R10.1, RESET_BUTTON.1, RESET_BUTTON.2, SENSOR2.1 (GND), SENSOR2.5 (SDO), SENSOR2.7 (GND), SJ1.1, TP4.TP, TP5.TP, U1.4 (GND), U1.9 (EXP), U2.1 (GND), U2.28 (GND), U2.29_1 (GND), U2.29_2 (GND), U2.29_3 (GND), U2.29_4 (GND), U2.29_5 (GND), U2.29_6 (GND), U2.29_7 (GND), U2.29_8 (GND), U2.29_9 (GND), U3.13 (GND), U4.1 (CTG), U4.4 (GND), U4.6 (QSTRT), U4.9 (EP)
GPIO8: R9.1, U2.10 (IO8)
I2C_PW: C2.1, C5.1, R1_PINH.2, R2-PINH.2, SENSOR2.2 (CSB), SENSOR2.6 (VDDIO), SENSOR2.8 (VDD), U2.17 (IO19)
INT_RTC: R1_PINH1.1, TP15.TP, U2.8 (IO0), U3.3 (SQW/!INT)
IO/BOOT: BOOT_BUTTON.3, BOOT_BUTTON.4, C10.1, R_BOOT.2, U2.15 (IO9)
IO/CHANGE: C11.1, CHANGE_BUTTON.3, CHANGE_BUTTON.4, R_CHANGE.2, U2.23 (IO15)
MISO: D2.1, J4.P7 (DAT0), R3.1, TP6.TP, U1.2 (DO(IO1)), U2.27 (IO2)
MOSI: D3.1, J1.14, J4.P3 (CMD), R4.1, TP7.TP, U1.5 (DI(IO0)), U2.7 (IO7)
unnamed: J2.A5, R2-USB1.2
unnamed: EPD_C12.1, J1.24
unnamed: D7.1 (CATHODE), R_CAPACITOR.1
unnamed: EPD_C10.1, J1.22
unnamed: EPD_C8.1, J1.20
unnamed: MCP73831.5 (PROG), R2_BAT.2
unnamed: EPD_C7.1, J1.19
unnamed: EPD_C6.1, J1.18
unnamed: J2.B5, R2-USB.1
unnamed: MCP73831.1 (STAT), R1_BAT.1
unnamed: EPD_C2.1, J1.5
unnamed: EPD_C1.1, J1.4
unnamed: C4.1, D10.2 (A), D11.1 (K)
unnamed: CHG_LED.C, R1_BAT.2
unnamed: C_DELAY.1, IC1.5 (CT)
unnamed: C1_BAT1.1, D9.1 (CATHODE), IC4.1 (VIN), IC4.3 (CE), Q1.2 (S)
PREVGH: D12.1 (K), EPD_C9.1, J1.21
PREVGL: D11.2 (A), EPD_C11.1, J1.23
RESE: J1.3, Q3.2 (S), R11.2
RESE': R1.2, R11.1, SJ1.2
RESET: C7.1, IC1.1 (VOUT), RESET_BUTTON.3, RESET_BUTTON.4, R_RESET.2, U2.3 (EN)
RTC_RST: U2.16 (IO18), U3.4 (!RST)
RX: TP2.TP, U2.24 (RXD0/GPIO17)
SCK: D4.1, J1.13, J4.P5 (CLK), R5.1, TP8.TP, U1.6 (CLK), U2.6 (IO6)
SCL: J3.4, R2-PINH.1, SENSOR2.4 (SCK), U2.20 (IO22), U3.16 (SCL), U4.7 (SCL)
SDA: J3.3, R1_PINH.1, SENSOR2.3 (SDI), U2.19 (IO21), U3.15 (SDA), U4.8 (SDA)
SRC: C4.2, D12.2 (A), L1.1, Q3.3 (D)
SS_SD: D8.1, J4.P2 (CD/DAT3), R8.1, U2.4 (IO4)
TX: TP1.TP, U2.25 (TXD0/GPIO16)
USB_D+: D1.4 (I/O2_2), U2.14 (IO13)
USB_D-: D1.6 (I/O1_2), U2.13 (IO12)
VBAT: C2_BAT.1, MCP73831.3 (VBAT), Q1.3 (D), TP3.TP, U4.2 (CELL), U4.3 (VDD)
VBUS: C1_BAT.1, C4_USB.1, C5_USB.1, CHG_LED.A, D1.2 (GND), D9.2 (ANODE), MCP73831.4 (VIN), Q1.1 (G), R1_PWRUSB.2, R2.2, TP14.TP
VRTC: C8.1, CPH3225A.1, R_CAPACITOR.2, U3.14 (VBAT)
VUSB: J2.A4, J2.A9, J2.B4, J2.B9, R2.1

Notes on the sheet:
USB C connector & ESD protection
LDO Voltage Regulator
Display Type Selector
E-Paper Drive Circuit
Li-Po Baterry Charging Controller
E-Paper Display Header
RTC Module DS3231SN
EPD Power
Test Pads
Environmental Sensor BME688
Qwiic / Stemma QT
SPI ESD Protection Lines
Voltage Supervisor + Reset & Boot / IO Button
Battery Charge Level
External NOR Flash 64MB
ESP32 C6
SD Card

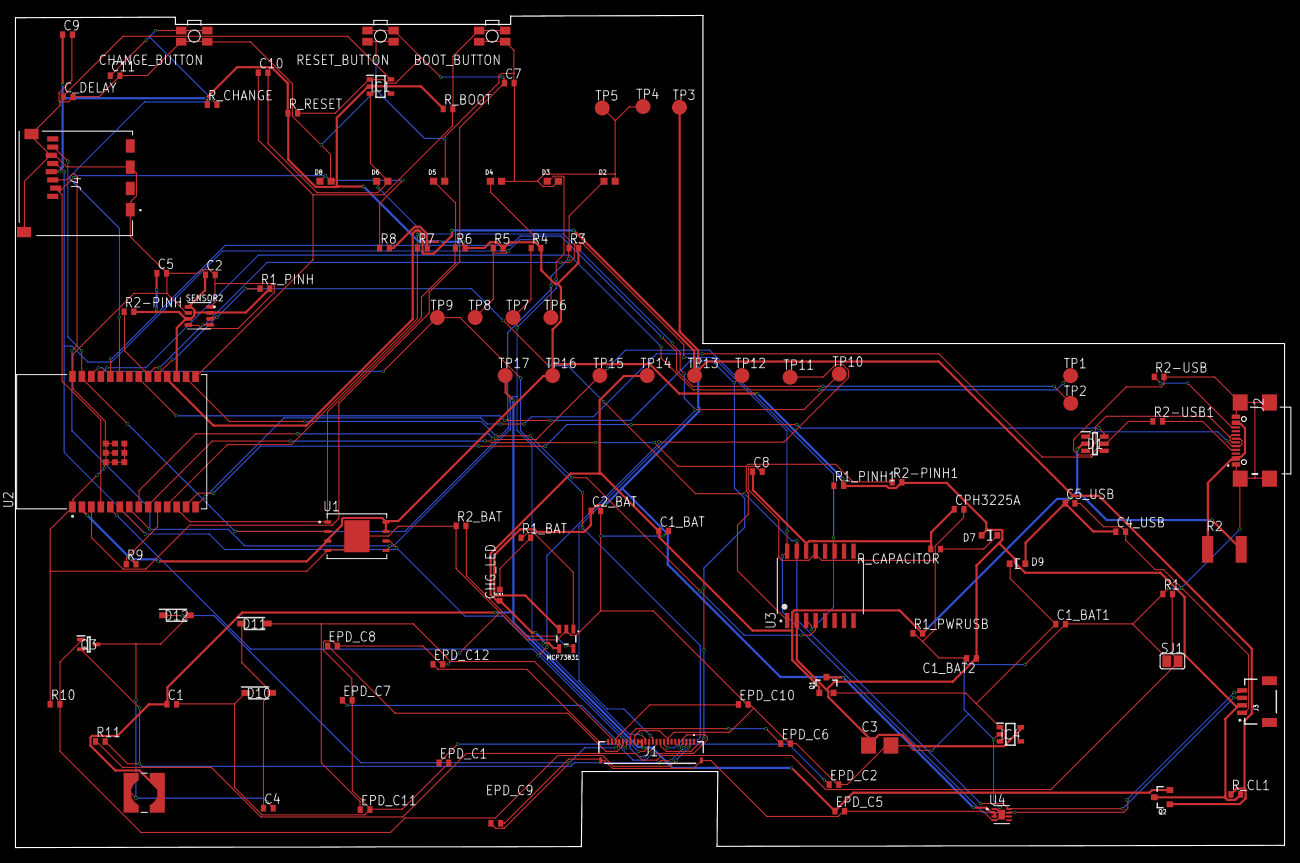
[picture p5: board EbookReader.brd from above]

Board: 2 copper layers, 170.2 x 111.6 mm, 103 parts (0 on the bottom side), 55 nets.

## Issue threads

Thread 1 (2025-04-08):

[PCB] Condensatoare de decuplare departate de pinii de alimentare

HoriaMercan, 2025-04-08:
Condensatoarele de decuplare (100nF) trebuie amplasate in proximitatea piniilor de alimentare.

Un exemplu sugestiv pentru issue:
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

In plus, nu sunt recomandate vias-uri pentru trasee de putere (in cazul acesta 3V3).

Closed 2025-04-14.

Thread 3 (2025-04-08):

[PCB] Numele semnalelor testpadurilor trebuie marcat in silkscreen

HoriaMercan, 2025-04-08:
Legat de sectiunea "observatii & recomandari", pct. 11

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

Intrucat test-pad urile sunt folosite in testare, numele semnalelor pus pe placuta langa testpaduri este util.
Posibila solutie:
Din alegi comanda  Document > Draw > Text si apoi te muti pe layerul SilkscreenTop.

Closed 2025-04-14.

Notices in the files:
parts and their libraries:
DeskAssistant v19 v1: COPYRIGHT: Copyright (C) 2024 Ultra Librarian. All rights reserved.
